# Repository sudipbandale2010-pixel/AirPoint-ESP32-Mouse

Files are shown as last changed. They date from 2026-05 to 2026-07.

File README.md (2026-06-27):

# AirPoint-ESP32-Mouse
This is an easy ESP32 Air mouse project which uses BLE (Bluetooth Low Energy) for connecting to any other devices like Laptop, PC, Smart TVs, Projectors, and even mobiles and tablets. So we can say that its universal Air mouse.

<details>
<summary>Bill of Materials (BOM)</summary>

| Item | Purpose | Source | Cost |
|---|---|---|---|
| ESP32 Dev Module | Main microcontroller | Amazon | $5.70 |
| 12x12mm Tactile Push Buttons (x4) | Left click, right click, scroll up, scroll down | Amazon | $0.87 |
| TP4056 Charging Module | Battery charging | Amazon | $1.32 |
| 3.7V Li-ion Battery (18650) | Power source | Amazon | $4.14 |
| MPU6050 Accelerometer/Gyroscope | Motion detection | Amazon | $3.00 |
| PLA Filament | 3D printed enclosure | Amazon | $7.25 |
| PCB | Custom circuit board | JLCPCB | $6.40 |
| **TOTAL COST** |  |  | **$25.39** |

</details>

Wiring diagram:-

PCB circuit

Once completing the circuit diagram and coding, I was wondering if it works, so I made a prototype version of AirPoint with breadboard.




Now the thing was, It worked perfectly but I had powered it with USB Cable and I wanted such battery which would give more power and for long time, so I started working on it.



And now, I was going to use the 18650 li-ion battery 3.7v with 3000mAh and Tp4056 charging module for charging which perfectly worked fine. 

Now the time was to make my own custom case for it, So I started designing one and it looked like this...



If you want, you can even change the colours of the case accordingly, as I have provided the file of CAD, you can now print the case with ease.

Now the thing is, I am using breadboard for the final project and you can too but if you are feeling lazy then you can use PCB too, so I have provided the PCB gerber files and it may cost around 6-7$ (Depends from where you are buying it,I used JLC PCB), This is how the PCB will look like...



(NOTE :- If you are really using PCB for project then do remember to attach wires from switch to the PCB as the PCB will be at the bottom of the case and Switch may not reach the sufficient height.)

That's it!!, You just created your own ESP32 based Air Mouse and now you are ready to use it. 

How to use it? 
Turn on the bluetooth of device(ex- phone or smart TV), and connect the device with AirPoint, You will see that the cursor is moving by the AirPoint, the upper two buttons are RMB and LMB, and the bottom and verticle buttons are for scrolling.

Why I built this:
For how long are we using the mouse which just rubs against the surface, to be futurastic, I made my own custom air mouse, AirPoint.

Here's the zine page of my Project....

Airpoint

see ya!!!! :)

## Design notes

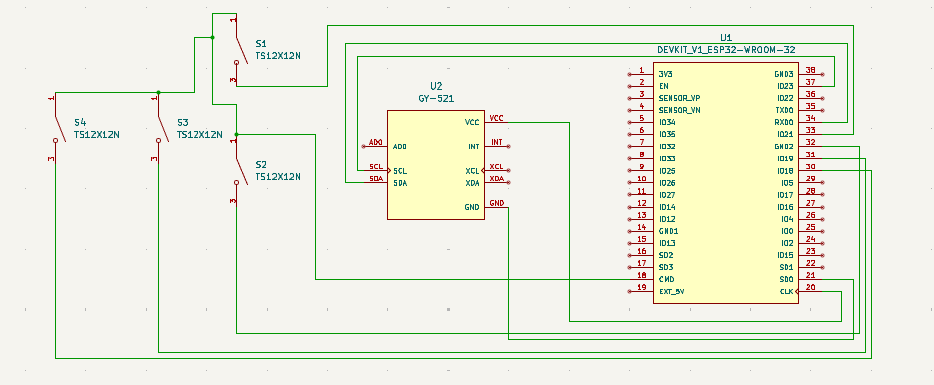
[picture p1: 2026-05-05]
Schematics/PCB circuit.png

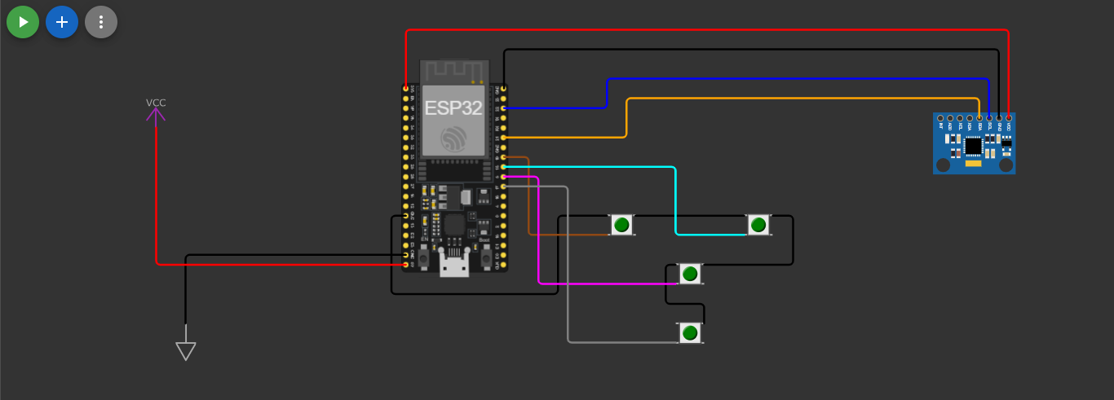
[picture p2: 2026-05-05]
Schematics/Circuit (1).png

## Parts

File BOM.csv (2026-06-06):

Item | Purpose | Source | Price | link
1.Esp32 Dev Module | main micro controller | Amazon | 5.7$ | https://www.amazon.in/Robocraze-ESP32-Development-Board-Pin/dp/B0D6GDV77P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
2.12x12mm Tactile Push Button x4 | for Left click right click acroll up scroll down | amazon | 0.87$ | https://www.amazon.in/Tactile-Push-Button-Switch-Round/dp/B09G2QJF5X
3.Tp4056 3.7v charging module | charging the battery | amazon | 1.32$ | https://www.amazon.in/Electronicspices-Lithium-Battery-Charging-Protection/dp/B08HQWJ58Z
4.3.7v li-ion battery (18650) | to power the product | amazon | 4.14$ | https://www.amazon.in/KP-Original-Rechargeable-Battery-Electronic/dp/B0GWVRSLWC
5.MPU6050 Accelerometer | for movement detections | amazon | 3.00$ | https://www.amazon.in/Robocraze-MPU-6050-Gyroscope-Accelerometer-Arduino/dp/B07H3XH1TB
6.PLA 3d printing Filament 1kg Black | for making the case | amazon | 7.25$ | https://www.amazon.in/PLA-3D-Flexibility-Eco-Friendly-Compatible/dp/B071D82LDV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
7.PCB | for embeding all components on one board | JlcPCB | 6.40$ | https://cart.jlcpcb.com/quote?spm=jlcpcb.Public.2006
8.Total |  |  | 25.39$

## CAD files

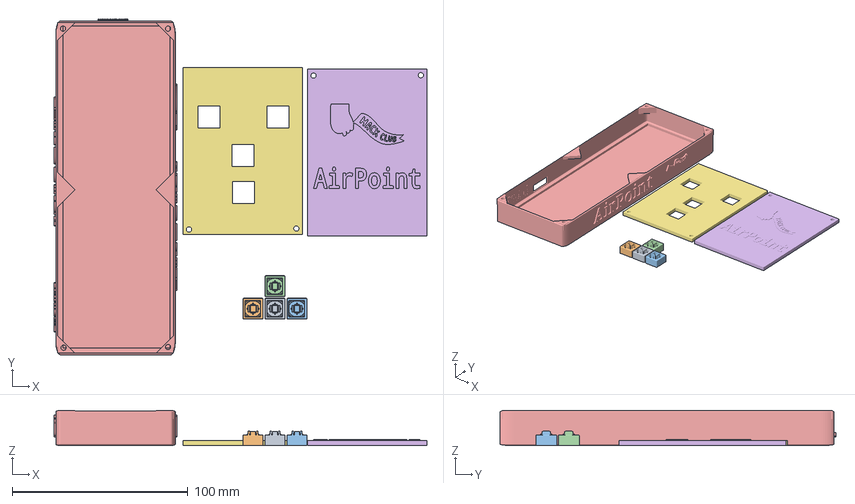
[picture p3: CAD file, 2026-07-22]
CAD/Full AirPoint CAD file.3mf
212.1 x 191.0 x 20.0 mm
ImageToStl.com_Button+caps.stl x 4
AirPoint Case.3mf.stl
AirPoint Case lead 2.stl
AirPoint Case holes for buttons.stl

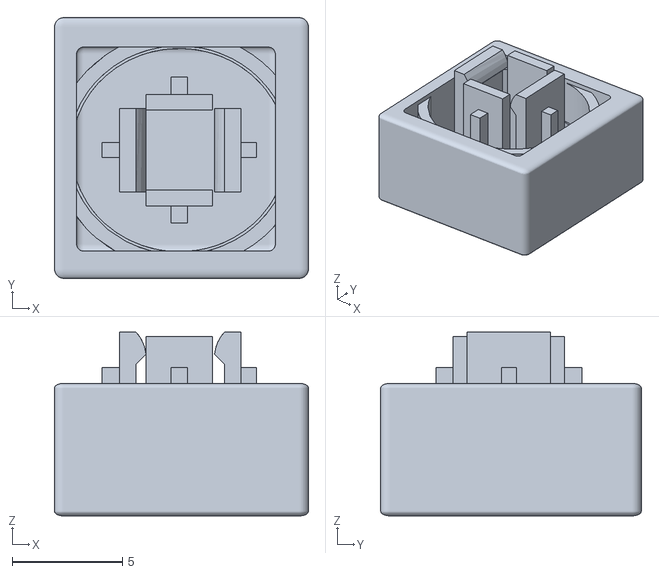
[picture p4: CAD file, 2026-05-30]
CAD/ImageToStl.com_Button+caps.stl
11.5 x 11.8 x 8.32

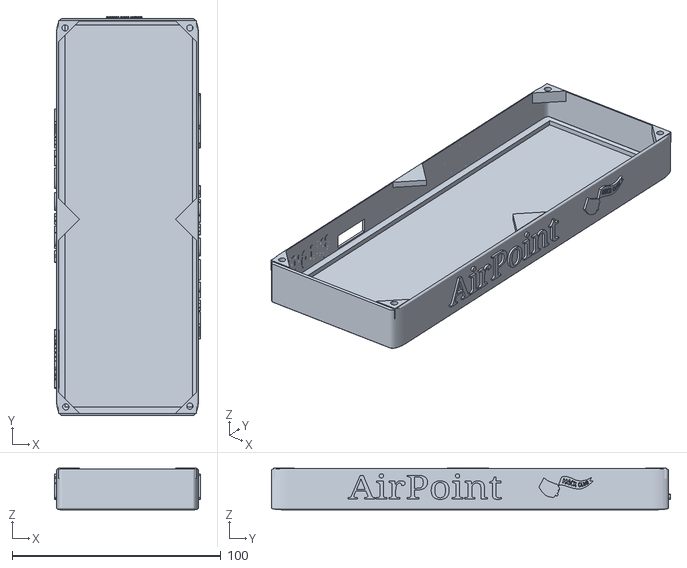
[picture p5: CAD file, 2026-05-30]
CAD/AirPoint Case.3mf.stl
70.0 x 191.0 x 20.0

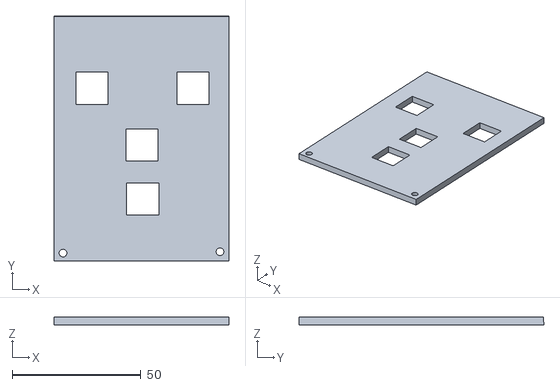
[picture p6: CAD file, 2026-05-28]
CAD/AirPoint Case holes for buttons.stl
68.0 x 95.0 x 3.00

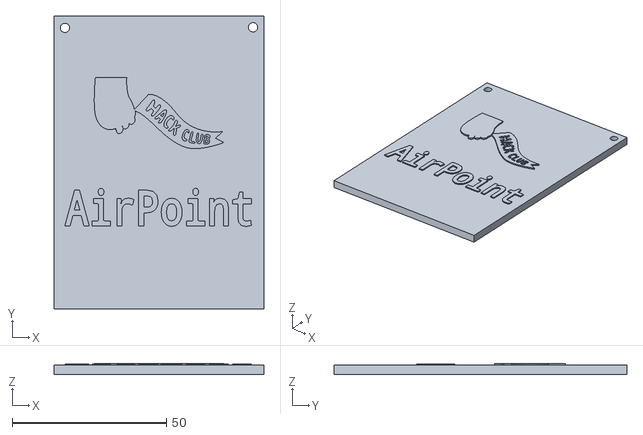
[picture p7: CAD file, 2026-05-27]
CAD/AirPoint Case lead 2.stl
68.0 x 95.0 x 3.50

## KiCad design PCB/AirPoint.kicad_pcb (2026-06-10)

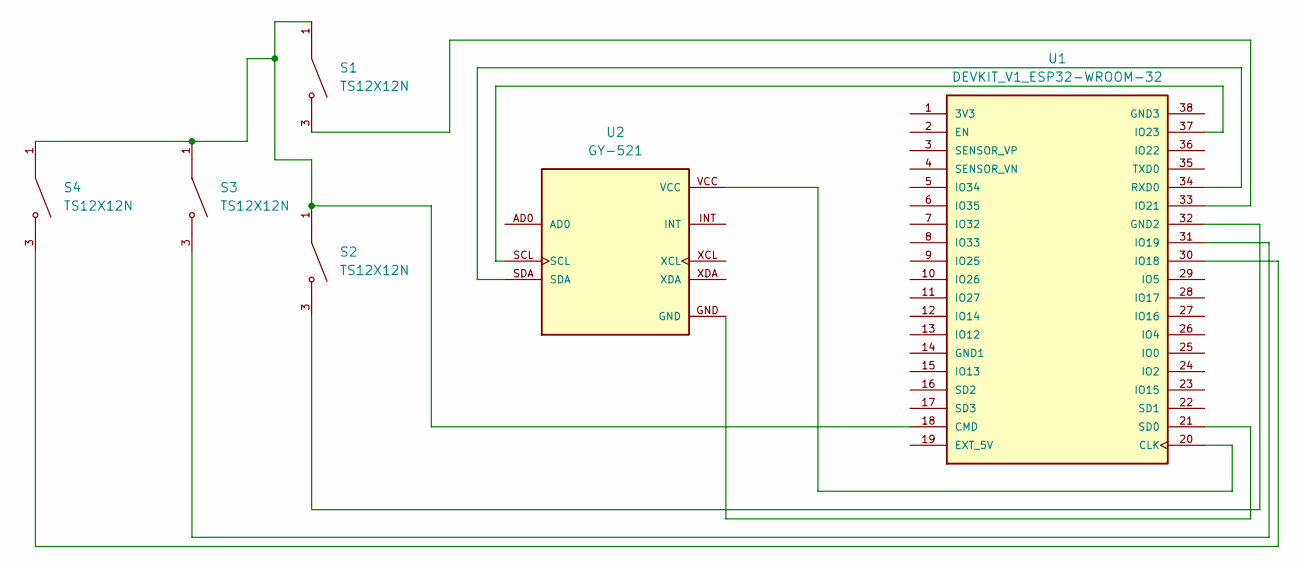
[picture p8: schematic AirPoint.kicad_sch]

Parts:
S1, S2, S3, S4: TS12X12N; SW_TS12X12N; PARTREV June 9, 2021
U1: DEVKIT_V1_ESP32-WROOM-32; MODULE_DEVKIT_V1_ESP32-WROOM-32; PARTREV N/A
U2: GY-521; MODULE_GY-521; PARTREV NA

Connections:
unnamed: U1.20 (CLK), U2.VCC
unnamed: S1.1, S1.2, S2.1, S2.2, S3.1, S3.2, S4.1, S4.2, U1.18 (CMD)
unnamed: S2.3, S2.4, U1.32 (GND2)
unnamed: S4.3, S4.4, U1.30 (IO18)
unnamed: S3.3, S3.4, U1.31 (IO19)
unnamed: S1.3, S1.4, U1.33 (IO21)
unnamed: U1.37 (IO23), U2.SCL
unnamed: U1.34 (RXD0), U2.SDA
unnamed: U1.21 (SD0), U2.GND

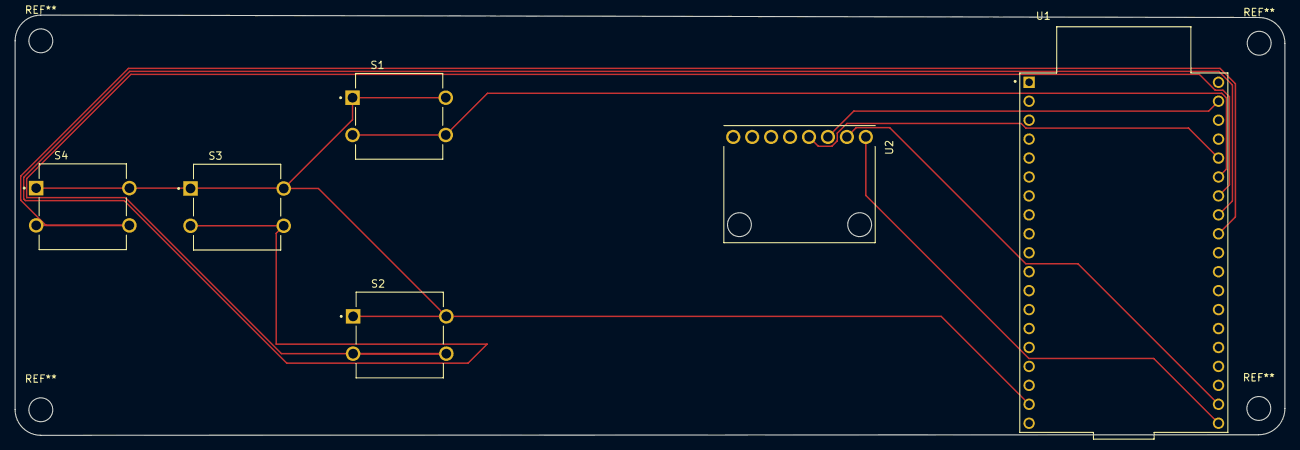
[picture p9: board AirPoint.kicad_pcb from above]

Board: 2 copper layers, 170.3 x 56.4 mm, 6 parts (0 on the bottom side), 9 nets.

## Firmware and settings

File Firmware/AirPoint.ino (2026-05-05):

#include <BleMouse.h>
#include <Wire.h>
#include <Adafruit_MPU6050.h>
#include <Adafruit_Sensor.h>

// Button pins
#define LEFT_BUTTON 19
#define RIGHT_BUTTON 18
#define SCROLL_UP_BUTTON 5
#define SCROLL_DOWN_BUTTON 17

// BLE Mouse
BleMouse bleMouse("AirPoint", "Sudip", 100);

// MPU6050
Adafruit_MPU6050 mpu;

// Sensitivity (Y is higher)
float sensitivityX = 3.5;
float sensitivityY = 7.5;

// Dead zone
float deadZone = 0.01;

// Smoothing
float smoothX = 0, smoothY = 0;
float alpha = 0.3;

unsigned long lastKeepAlive = 0;

void setup() {
  Serial.begin(115200);

  pinMode(LEFT_BUTTON, INPUT_PULLUP);
  pinMode(RIGHT_BUTTON, INPUT_PULLUP);
  pinMode(SCROLL_UP_BUTTON, INPUT_PULLUP);
  pinMode(SCROLL_DOWN_BUTTON, INPUT_PULLUP);

  Wire.begin(21, 22);

  if (!mpu.begin()) {
    Serial.println("MPU6050 not found!");
    while (1);
  }

  mpu.setAccelerometerRange(MPU6050_RANGE_8_G);
  mpu.setGyroRange(MPU6050_RANGE_500_DEG);
  mpu.setFilterBandwidth(MPU6050_BAND_21_HZ);

  bleMouse.begin();
  delay(2000);
}

void loop() {
  if (bleMouse.isConnected()) {

    sensors_event_t a, g, temp;
    mpu.getEvent(&a, &g, &temp);

    // Raw gyro movement
    float rawX = g.gyro.y * sensitivityX;
    float rawY = -g.gyro.x * sensitivityY;

    // Dead zone
    if (abs(rawX) < deadZone) rawX = 0;
    if (abs(rawY) < deadZone) rawY = 0;

    // Smoothing
    smoothX = (alpha * rawX) + ((1 - alpha) * smoothX);
    smoothY = (alpha * rawY) + ((1 - alpha) * smoothY);

    int moveX = (int)smoothX;
    int moveY = (int)smoothY;

    // Minimum movement (Windows fix)
    if (moveX != 0) moveX = (moveX > 0) ? max(1, moveX) : min(-1, moveX);
    if (moveY != 0) moveY = (moveY > 0) ? max(1, moveY) : min(-1, moveY);

    // Move or keep alive
    if (moveX == 0 && moveY == 0) {
      bleMouse.move(0, 0);
    } else {
      bleMouse.move(moveX, moveY);
    }

    // LEFT CLICK
    if (digitalRead(LEFT_BUTTON) == LOW) {
      bleMouse.press(MOUSE_LEFT);
    } else {
      bleMouse.release(MOUSE_LEFT);
    }

    // RIGHT CLICK
    if (digitalRead(RIGHT_BUTTON) == LOW) {
      bleMouse.press(MOUSE_RIGHT);
    } else {
      bleMouse.release(MOUSE_RIGHT);
    }

    // SCROLL UP
    if (digitalRead(SCROLL_UP_BUTTON) == LOW) {
      bleMouse.move(0, 0, 1);
      delay(80);
    }

    // SCROLL DOWN
    if (digitalRead(SCROLL_DOWN_BUTTON) == LOW) {
      bleMouse.move(0, 0, -1);
      delay(80);
    }

    // Keep-alive
    if (millis() - lastKeepAlive > 1000) {
      bleMouse.move(0, 0);
      lastKeepAlive = millis();
    }

    delay(5);
  }
}
